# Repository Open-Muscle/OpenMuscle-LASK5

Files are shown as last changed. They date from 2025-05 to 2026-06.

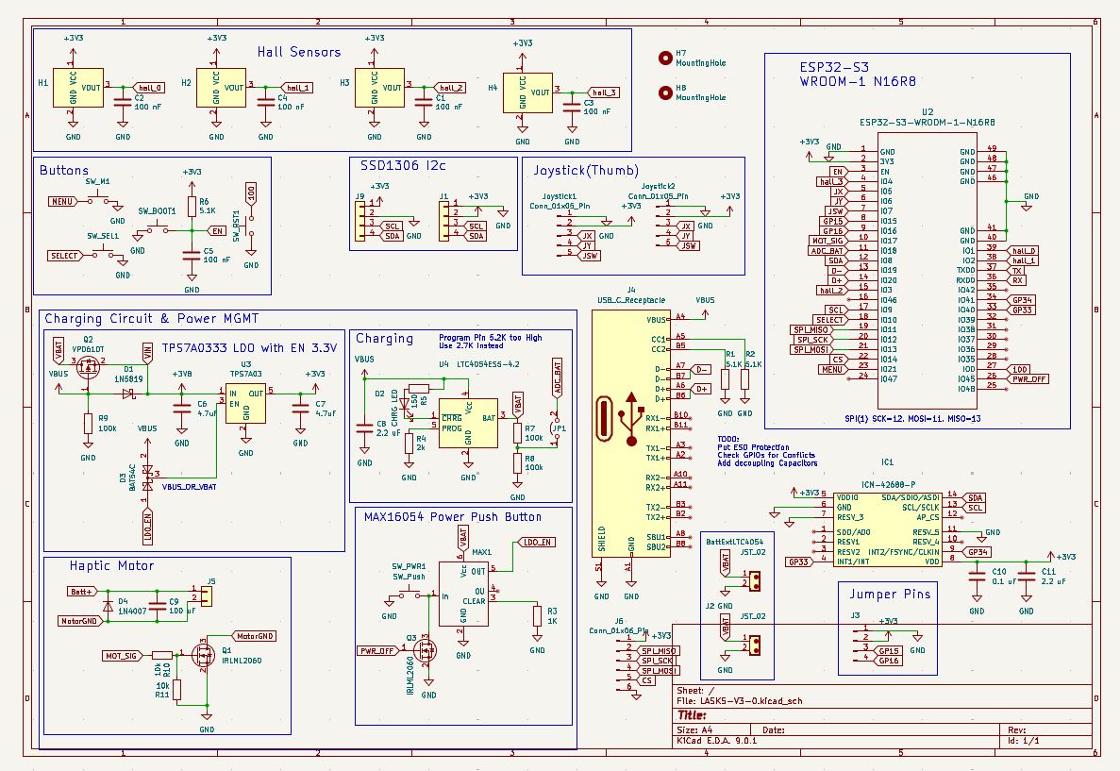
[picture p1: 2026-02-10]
Schematics/Open Muscle Labeler (LASK5) Schematic-V3.jpg

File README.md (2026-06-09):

# LASK5 – A Gloveless Smart Glove Controller






LASK5 is a compact, gloveless smart glove controller designed for robotics, machine learning, and human-computer interaction projects. Originally created to assist with labeling movement data for the [OpenMuscle](https://openmuscle.org) project, this controller is now a fully open-source interface capable of controlling robotic hands, LED sculptures, and more.

```markdown
📌 This device is part of the OpenMuscle ecosystem.  
For project-wide documentation, visit the [OpenMuscle Hub](https://github.com/Open-Muscle/OpenMuscle-Hub).
```

---

## 📽️ Watch the Demo

🎥 **YouTube Video:** [LASK5: The Gloveless Smart Glove](https://youtu.be/DJxaf0ww6us)

---

## 🔧 Features

- ESP32-S3 based (Wi-Fi + ESP-NOW enabled)
- 4-piston finger input with hall sensors
- Thumb joystick
- 128x32 OLED display for menus and feedback
- 4 SMD buttons for UI control
- Modular headers for add-ons (gyroscope, additional sensors)
- Written in MicroPython
- 3D-printable enclosure

---

## 🗂️ Repository Structure

### 🛠️ Hardware (KiCad)

You can find all historical and current KiCad hardware designs under:

📂 [`KiCad/`](https://github.com/Open-Muscle/OpenMuscle-LASK5/tree/main/KiCad)

Each folder contains complete KiCad files, BOMs, and version-specific layout changes.

| Version | Description | Folder |
|---|---|---|
| **v3.0** (Proposed) | New layout with joystick, button updates | [LASK_V3-0](https://github.com/Open-Muscle/OpenMuscle-LASK5/tree/main/KiCad/LASK_V3-0) |
| v2.0 | Button layout revision, early joystick test | [LASK_V2-0](https://github.com/Open-Muscle/OpenMuscle-LASK5/tree/main/KiCad/LASK_V2-0) |
| v1.1 | Original layout with 3-button config | [LASK_V1-1](https://github.com/Open-Muscle/OpenMuscle-LASK5/tree/main/KiCad/LASK_V1-1) |

🧩 Component footprints are stored in:
- [`ESP32WROOMfootprint`](https://github.com/Open-Muscle/OpenMuscle-LASK5/tree/main/KiCad/ESP32WROOMfootprint)
- [`USBfootprint`](https://github.com/Open-Muscle/OpenMuscle-LASK5/tree/main/KiCad/USBfootprint)
- [`ICM-42688-P`](https://github.com/Open-Muscle/OpenMuscle-LASK5/tree/main/KiCad/ICM-42688-P)

---

### 💾 Firmware

The firmware for all LASK versions is maintained centrally in:

📂 [OpenMuscle-Software → `/embedded/lask5`](https://github.com/Open-Muscle/OpenMuscle-Software/tree/main/embedded/LASK5)

> ✅ Be sure to match the firmware branch or directory with your hardware version (see notes in the firmware repo for version compatibility).

---

## 🧠 Use Cases

- Robotic hand control (e.g. HiWonder, Arduino-powered systems)
- LED and kinetic art control
- Machine learning data labeling (OpenMuscle)
- Custom HCI devices, VR/AR control experiments

---

## 🚀 Getting Started

1. Visit the [OpenMuscle Hub](https://github.com/Open-Muscle/OpenMuscle-Hub) for device setup overview.
2. Select your hardware version from the `/KiCad` folder.
3. Follow included assembly instructions (or upcoming guides at [openmuscle.org](https://openmuscle.org)).
4. Flash your ESP32-S3 using the LASK5 firmware from [OpenMuscle-Software](https://github.com/Open-Muscle/OpenMuscle-Software).
5. Power on, test input, and begin using ESP-NOW or serial modes.

---

## 🤝 Contribute

We welcome PRs for hardware, firmware, or documentation.  
You can also submit ideas or questions in [OpenMuscle Discussions](https://github.com/Open-Muscle/OpenMuscle-Hub/discussions) (coming soon).

> If you build your own LASK5 device, let us know!  
> Tag [@OpenMuscle](https://github.com/Open-Muscle) or submit to the Community Builds section.

---

## 📜 License

This repository is covered by a combination of licenses based on content type:

- **Hardware Design Files** (KiCad schematics, PCB layouts, mechanical files):  
  📄 [CERN Open Hardware License v2.0 – Strongly Reciprocal (CERN-OHL-S)](https://ohwr.org/cern_ohl_s_v2.txt)  
  → You may copy, modify, and manufacture hardware as long as you release modifications under the same license.

- **Firmware and Code Snippets** (e.g. MicroPython, setup scripts):  
  📄 [MIT License](https://opensource.org/licenses/MIT)  
  → You may use, modify, and redistribute the code freely with attribution.

- **Art and Visual Media** (e.g. logos, SVGs, diagrams, illustrations):  
  🎨 [Creative Commons Attribution 4.0 International (CC BY 4.0)](https://creativecommons.org/licenses/by/4.0/)  
  → You may use and remix art assets with credit to the original authors.
  
🔍 The hardware license text lives at [LICENSE](LICENSE) (root) and in [LICENSES/](LICENSES/).

---

Made with 💡 by [TURFPTAx](https://github.com/turfptax) for the OpenMuscle initiative.

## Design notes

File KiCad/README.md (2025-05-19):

# LASK5 – OpenMuscle Sensor Device

**Version:** `V3 (Proposed)`  
**Target Microcontroller:** ESP32-S3-WROOM-1-N16R8  
**Project:** OpenMuscle – Biomechanical Sensing for Prosthetics & Robotics  
**Repository:** https://github.com/turfptax/OpenMuscle-Hardware

---

## 📐 Overview

The LASK5 board is a wearable sensor platform for real-time finger movement detection, developed as part of the OpenMuscle project. It integrates Hall effect sensors, a joystick, buttons, a low-power screen, and wireless communication via ESP32-S3.

Version 3 introduces multiple improvements in usability, sensing accuracy, and expandability.

---

## 🚀 New in V3 (Proposed)

| Feature | Description |
|---|---|
| 🔌 USB Detection | VBUS now routed to a GPIO via voltage divider, allowing firmware to detect USB connection. |
| 🔋 USB Boot Without Battery | Modified power logic enables powering on via USB without a battery installed, using diode-based OR logic to control LDO enable line. |
| 📉 Improved ADC Accuracy | Voltage divider for battery monitoring updated to 10k/10k, reducing impedance for better ESP32-S3 ADC readings. |
| 🧭 6-Axis Gyroscope Support | IMU footprint and I²C headers added for optional motion sensing (MPU6050 or ICM-42688). |
| ⚙️ Charging Status Feedback | CHRG pin from LTC4054 connected to GPIO for in-software charge status indication. |

---
## 📦 Block Diagram
```
Battery ─────┐
├─> Charger (LTC4054) ──> Power Rail (+3.3V)
USB ───────┐ │
│ └─> VBUS GPIO (USB Detect)
└───> LDO EN Logic ──> TPS7A0333 LDO ──> ESP32-S3
```
---

## 📊 Hardware Specifications

- **MCU:** ESP32-S3-WROOM-1-N16R8 (dual-core, WiFi/BLE, 16MB flash, 8MB PSRAM)
- **Power:**
  - USB-C with VBUS detection
  - 1-cell LiPo battery
  - TPS7A0333 LDO (3.3V, low quiescent current)
  - MAX16054 latched soft-power button
- **Sensing:**
  - 4x Hall effect analog sensors
  - 1x Joystick (XY + button)
  - 0.96” SSD1306 OLED display (I²C)
  - Optional 6-axis gyro (MPU6050, ICM-42688, etc.)
- **Inputs:**
  - `menu` and `select` tactile buttons
  - Power button
- **Charging:**
  - LTC4054ES5-4.2 Li-Ion charger
  - CHRG status indicator routed to GPIO
- **Communication:**
  - ESP-NOW, WiFi, BLE
- **Headers:**
  - I²C breakout
  - SPI/debug/jumper expansion

---

## 🛠️ Setup & Firmware

- Flash via USB-C using esptool or Micropython.
- Default I²C pins: `SDA=GPIO15`, `SCL=GPIO16`
- ADC battery read: `GPIO4` (adjusted via voltage divider)
- USB detect pin: `GPIO10` *(example)*
- CHRG detect pin: `GPIO11` *(example)*

---

## 📚 Resources

- [OpenMuscle.org](https://openmuscle.org)
- [KiCad Schematic Viewer](https://kicad.org)
- [ESP32-S3 Datasheet](https://www.espressif.com/sites/default/files/documentation/esp32-s3_datashee---

## 🙌 Contributing

Interested in testing or improving the hardware? Submit a pull request or open an issue with your suggestions.

---

## 🧪 Version History

| Version | Date | Notes |
|---|---|---|
| V1 | 2024-02 | Initial prototype, using ESP32-S3 Dev-Kit |
| V2 | 2024-05 | 4-Layer PCB with 4x1 Hall sensors & Joystick |
| V3 | 25-XX | USB logic, gyro, and ADC improvements |

---

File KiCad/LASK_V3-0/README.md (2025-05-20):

# LASK v3 – OpenMuscle Labeler PCB

**Version:** 3.0  
**KiCad Version:** 9.0.1  
**Project Type:** Embedded hardware (ESP32-based controller)  
**Use Case:** Labeling hand movement data for prosthetic machine learning models

This is the third iteration of the LASK (Labeler for Sensor Kit) PCB, designed as part of the OpenMuscle project. LASK v3 is a handheld device used to interact with muscle sensors, label data, and provide haptic and motion feedback during training sessions.

---

## 🧠 Major Additions in v3

- ✅ Added **haptic motor driver** with flyback diode protection  
- ✅ Added **ICM-42688-P IMU** (I²C, with alternate support for SPI)  
- ✅ Enhanced **power management** using a push-button latch and USB auto-power-on  
- ✅ Clean GPIO assignments for consistent firmware development

---

## 🧩 System Overview

| Subsystem | Description |
|---|---|
| **MCU** | ESP32-S3-WROOM-1 (16MB flash, 8MB PSRAM) |
| **Sensors** | 4x Hall effect sensors w/ 100nF capacitors to ground |
| **IMU** | ICM-42688-P (I²C: GPIO8=SDA, GPIO9=SCL) |
| **Display** | SSD1306 OLED (I²C shared) |
| **Input** | 2 buttons (Menu & Select), Thumb joystick w/ push |
| **Output** | Haptic motor driven via MOSFET on GPIO17 |
| **Power** | MAX16054 latch, TPS7A0333 LDO, LTC4054 charger |
| **Interface** | USB-C for charging and programming |

---

## 🧷 GPIO Pinout

| Function | GPIO |
|---|---|
| Hall Sensor 0 | 1 |
| Hall Sensor 1 | 2 |
| Hall Sensor 2 | 3 |
| Hall Sensor 3 | 4 |
| Joystick X | 5 |
| Joystick Y | 6 |
| Joystick Switch | 7 |
| I²C SDA (IMU + OLED) | 8 |
| I²C SCL (IMU + OLED) | 9 |
| Select Button | 10 |
| SPI MISO | 11 |
| SPI SCK | 12 |
| SPI MOSI | 13 |
| Haptic Motor Signal | 17 |
| Battery Voltage ADC | 18 |
| Menu Button | 21 |
| SPI CS (available) | 22 |

---

## 🔋 Power Management

- **Charging:** LTC4054 linear charger via USB-C  
- **Voltage Regulation:** TPS7A0333 LDO with EN pin control  
- **Power-on Logic:** MAX16054 handles push-button latching  
  - **VBUS detection** auto-enables LDO via diode OR circuit  
  - Power can also be toggled with push button  
- **Haptic Driver:** IRLML2060 N-MOSFET, protected by 1N4007 diode

---

## 🛠️ Schematic

LASK v3 Schematic  
> 📁 Located in `/kicad_project/`

---

## 🧪 Development Notes

- Future version may migrate IMU to SPI for better performance
- USB VBUS is sensed to allow automatic boot when plugged in
- Add decoupling capacitors on IMU pins for improved stability (see TODO in schematic)

---

## 📂 Repository Structure

```
/
├── kicad_project/
│ ├── LASKS-V3_0.kicad_sch
│ └── LASKS-V3_0.kicad_pcb
├── docs/
│ └── lask_v3_schematic.png
├── README.md
```

---

## 🔓 License

Open-source under [CERN-OHL-W v2](https://ohwr.org/project/cernohl/wikis/CERN-OHL-version-2)  
Part of the [OpenMuscle Project](https://openmuscle.org)

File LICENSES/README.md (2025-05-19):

# License Overview – OpenMuscle LASK5

This repository contains **open source hardware** and **firmware** developed as part of the OpenMuscle project.

## 🧩 Hardware License

All KiCad PCB files, schematic files, and mechanical designs in this repository are licensed under the:

📄 **CERN Open Hardware License v2 – Strongly Reciprocal (CERN-OHL-S)**  
You can copy, modify, and distribute the hardware as long as you share source files under the same license.

Full license text: [`LICENSES/CERN-OHL-S-2.0.txt`](./LICENSES/CERN-OHL-S-2.0.txt)  
More info: [https://ohwr.org/cern_ohl](https://ohwr.org/cern_ohl)

> Attribution Required: Please credit the OpenMuscle project in derivative works or publications.

## 💾 Firmware License

Firmware and MicroPython code is licensed under the permissive:

📄 **MIT License**

You can use this code freely in commercial or personal projects with attribution.

Full text: [`LICENSES/MIT.txt`](./LICENSES/MIT.txt)

## 📚 Documentation

If not explicitly stated, all written documentation (README files, build instructions, etc.) is shared under **CERN-OHL-S v2.0** along with the hardware.

## 🤝 Contributing

By contributing, you agree to license your work under the same terms.

For any questions about licensing or commercial reuse, contact: [https://openmuscle.org](https://openmuscle.org)

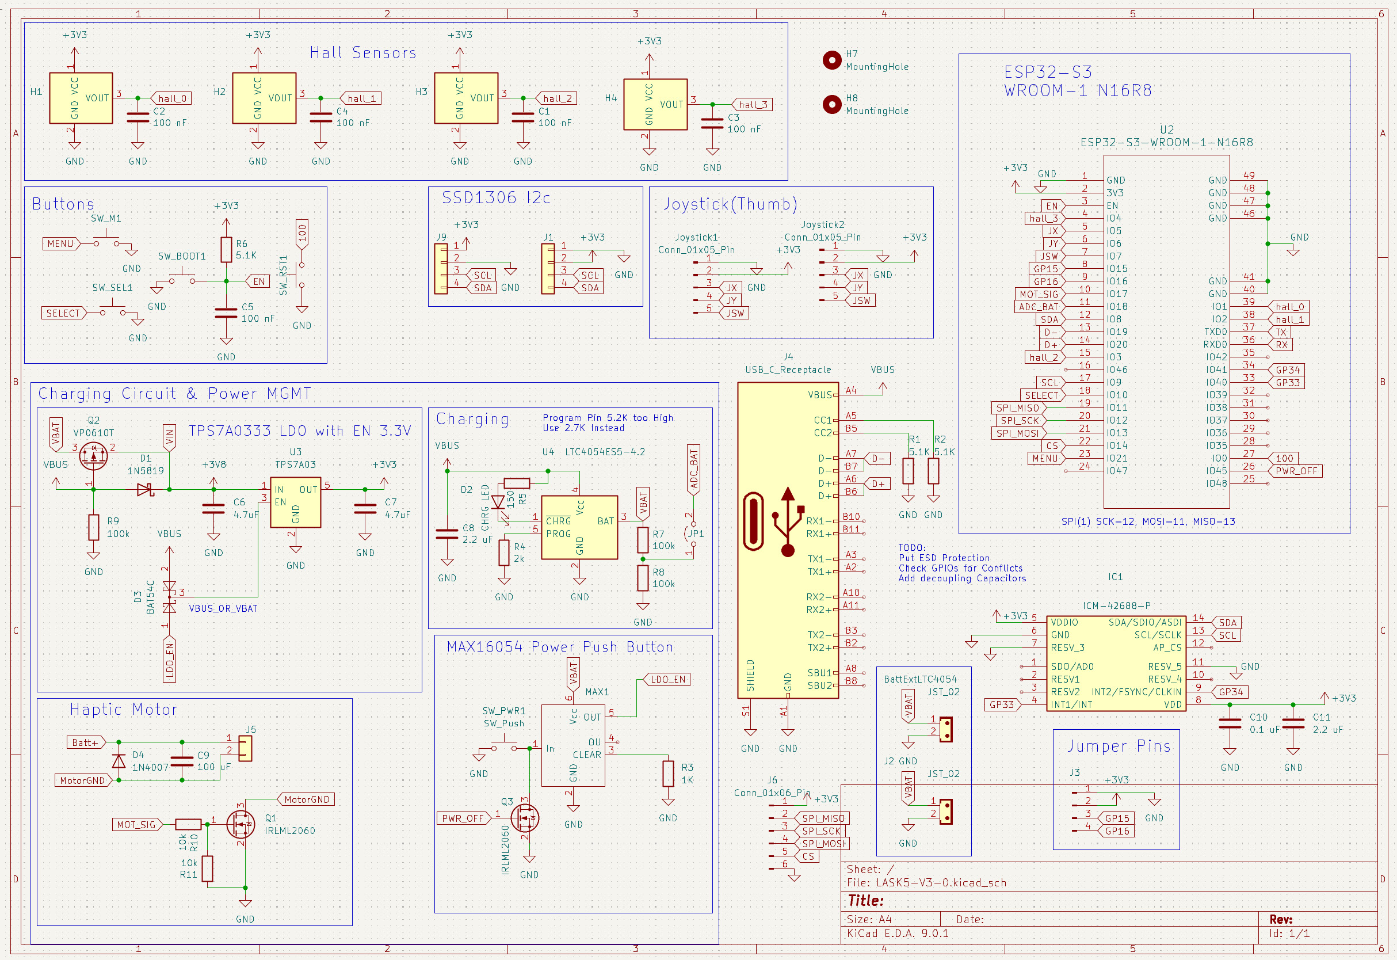
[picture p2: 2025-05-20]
KiCad/LASK_V3-0/images/LASK5-V3-Schematic.jpg

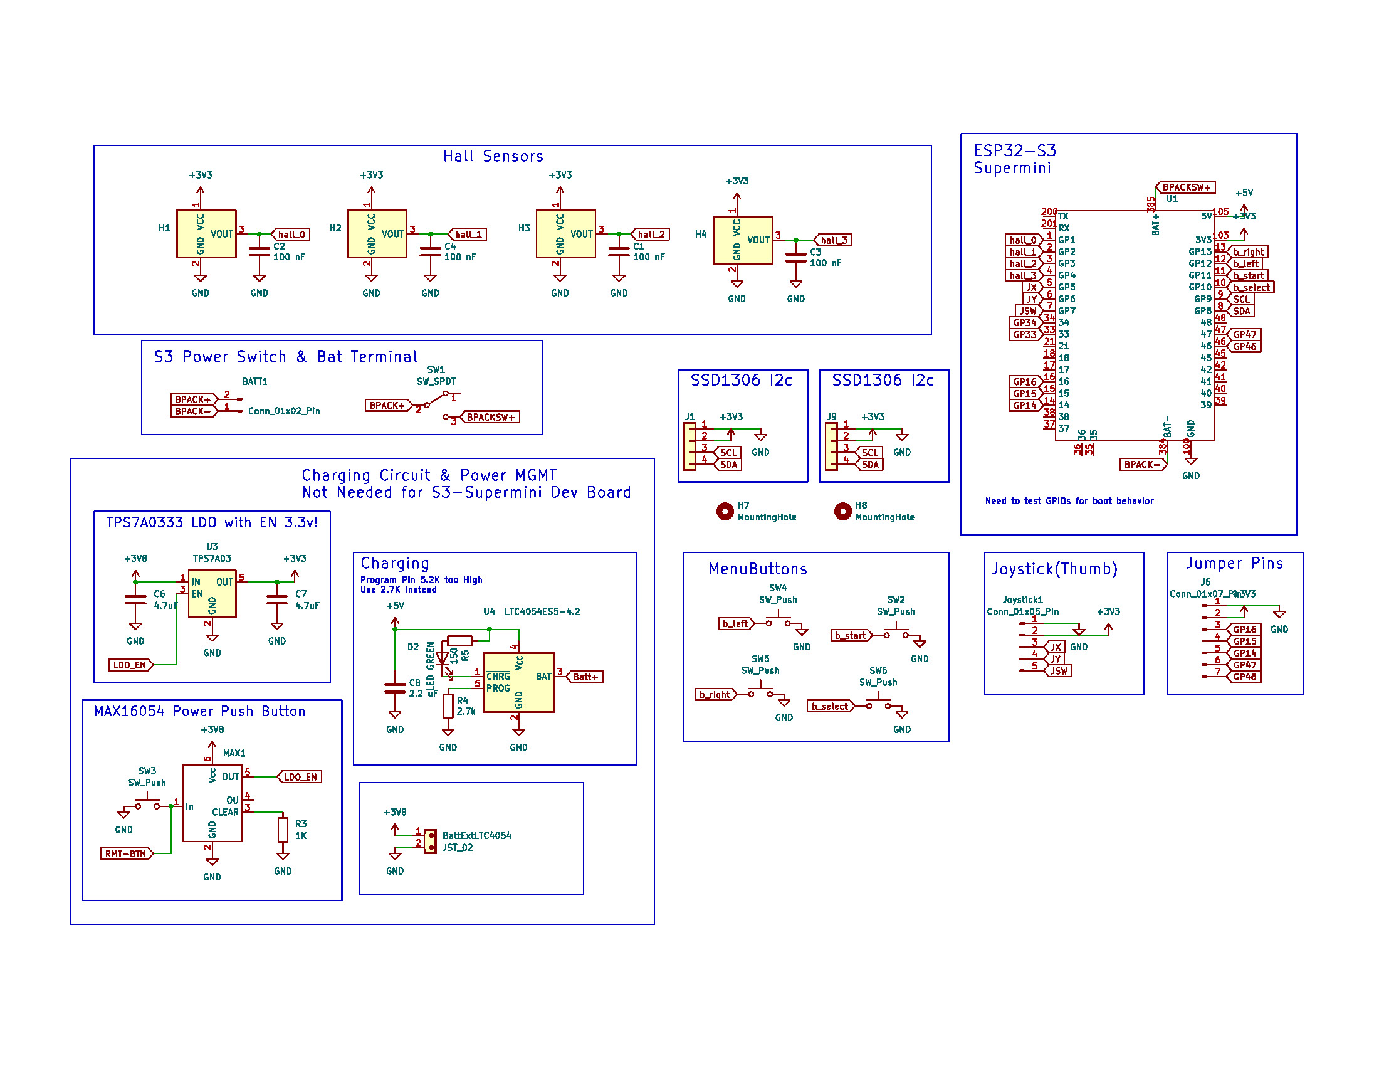
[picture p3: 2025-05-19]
Schematics/Open Muscle Labeler (LASK5) Schematic.jpg

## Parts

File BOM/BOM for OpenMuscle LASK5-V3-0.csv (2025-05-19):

Source: | D:\MT2-TX\OneDrive - TURFPTAx\Documents\GitHub\OpenMuscle-LASK5\KiCad\LASK_V3-0\LASK5-V3-0.kicad_sch
Date: | 2025-05-19T15:46:47-0500
Tool: | Eeschema 9.0.1
Generator: | C:\Program Files\KiCad\9.0\bin\scripting\plugins/bom_csv_grouped_by_value_with_fp.py
Component Count: | 56
Ref | Qnty | Value | Cmp name | Footprint | Description | Vendor | DNP
BattExtLTC4054 | 1 | JST_02 | JST_02 | Connector_JST:JST_EH_B2B-EH-A_1x02_P2.50mm_Vertical | JST Connector 2 pins
C1, C2, C3, C4, C5 | 5 | 100 nF | C | Capacitor_SMD:C_0402_1005Metric | Unpolarized capacitor
C6, C7 | 2 | 4.7uF | C | Capacitor_SMD:C_0805_2012Metric | Unpolarized capacitor
C8, C11 | 2 | 2.2 uF | C | Capacitor_SMD:C_0603_1608Metric | Unpolarized capacitor
C9 | 1 | 100 uF | C | Capacitor_SMD:C_0603_1608Metric | Unpolarized capacitor
C10 | 1 | 0.1 uF | C | Capacitor_SMD:C_0603_1608Metric | Unpolarized capacitor
D1 | 1 | 1N5819 | 1N5819 | Diode_SMD:D_SOD-123F | 40V 1A Schottky Barrier Rectifier Diode, DO-41
D2 | 1 | CHRG LED | LED | LED_SMD:LED_0805_2012Metric | LED generic
D3 | 1 | BAT54C | BAT54C | Package_TO_SOT_SMD:SOT-23 | dual schottky barrier diode, common cathode
D4 | 1 | 1N4007 | 1N4007 | Diode_SMD:D_SOD-123 | 1000V 1A General Purpose Rectifier Diode, DO-41
H1, H2, H3, H4 | 4 | A1369xUA-10 | A1369xUA-10 | Connector_PinHeader_2.00mm:PinHeader_1x03_P2.00mm_Vertical | Programmable Linear Hall Effect Sensor, -8.5 to -12.5mV/G, SIP-3
H7, H8 | 2 | MountingHole | MountingHole | MountingHole:MountingHole_2.2mm_M2 | Mounting Hole without connection
IC1 | 1 | ICM-42688-P | ICM-42688-P | IIM42352 | IMU 6-Axis
J1, J9 | 2 | Conn_01x04 | Conn_01x04 | Connector_PinHeader_2.54mm:PinHeader_1x04_P2.54mm_Vertical | Generic connector, single row, 01x04, script generated (kicad-library-utils/schlib/autogen/connector/)
J2 | 1 | JST_02 | JST_02 | Connector_JST:JST_EH_B2B-EH-A_1x02_P2.50mm_Vertical | JST Connector 2 pins
J3 | 1 | Conn_01x04_Pin | Conn_01x04_Pin | Connector_PinHeader_2.00mm:PinHeader_1x04_P2.00mm_Vertical | Generic connector, single row, 01x04, script generated
J4 | 1 | USB_C_Receptacle | USB_C_Receptacle | Connector_USB:USB_C_Receptacle_HRO_TYPE-C-31-M-12 | USB Full-Featured Type-C Receptacle connector
J5 | 1 | Conn_01x02 | Conn_01x02 | Connector_PinHeader_2.00mm:PinHeader_1x02_P2.00mm_Vertical | Generic connector, single row, 01x02, script generated (kicad-library-utils/schlib/autogen/connector/)
J6 | 1 | Conn_01x06_Pin | Conn_01x06_Pin | Connector_PinHeader_1.27mm:PinHeader_1x06_P1.27mm_Vertical | Generic connector, single row, 01x06, script generated
Joystick1, Joystick2 | 2 | Conn_01x05_Pin | Conn_01x05_Pin | Connector_PinHeader_2.00mm:PinHeader_1x05_P2.00mm_Vertical | Generic connector, single row, 01x05, script generated
JP1 | 1 | Jumper_2_Open | Jumper_2_Open | Jumper:SolderJumper-2_P1.3mm_Open_TrianglePad1.0x1.5mm | Jumper, 2-pole, open
MAX1 | 1 | MAX16054AZT | MAX16054 | Package_TO_SOT_SMD:SOT-23-6
Q1, Q3 | 2 | IRLML2060 | IRLML2060 | Package_TO_SOT_SMD:SOT-23 | 1.2A Id, 60V Vds, 480mOhm Rds, N-Channel HEXFET Power MOSFET, SOT-23
Q2 | 1 | VP0610T | VP0610T | Package_TO_SOT_SMD:SOT-23 | -0.18A Id, -60V Vds, P-Channel MOSFET, SOT-23
R1, R2, R6 | 3 | 5.1K | R | Resistor_SMD:R_0603_1608Metric | Resistor
R3 | 1 | 1K | R | Resistor_SMD:R_0603_1608Metric | Resistor
R4 | 1 | 2k | R | Resistor_SMD:R_0603_1608Metric | Resistor
R5 | 1 | 150 | R | Resistor_SMD:R_0603_1608Metric | Resistor
R7, R8, R9 | 3 | 100k | R | Resistor_SMD:R_0603_1608Metric | Resistor
R10, R11 | 2 | 10k | R | Resistor_SMD:R_0603_1608Metric | Resistor
SW_BOOT1 | 1 | SW_Push | SW_Push | OpenMuscleDevKit:EVQP2P02M | Push button switch, generic, two pins
SW_M1 | 1 | SW_Push | SW_Push | OpenMuscleDevKit:EVQP2P02M | Push button switch, generic, two pins
SW_PWR1 | 1 | SW_Push | SW_Push | OpenMuscleDevKit:EVQP2P02M | Push button switch, generic, two pins
SW_RST1 | 1 | SW_Push | SW_Push | OpenMuscleDevKit:EVQP2P02M | Push button switch, generic, two pins
SW_SEL1 | 1 | SW_Push | SW_Push | OpenMuscleDevKit:EVQP2P02M | Push button switch, generic, two pins
U2 | 1 | ESP32-S3-WROOM-1-N16R8 | ESP32-S3-WROOM-1-N16R8 | footprints:ESP32-S3-WROOM-1_EXP
U3 | 1 | TPS7A03 | TPS7A0508PDBV | Package_TO_SOT_SMD:SOT-23-5 | 200-mA Ultra-Low-Iq LDO, 0.8V, SOT-23-5
U4 | 1 | LTC4054ES5-4.2 | LTC4054ES5-4.2 | Package_TO_SOT_SMD:TSOT-23-5 | Constant-current/constant-voltage linear charger for single cell lithium-ion batteries with 2.9V Trickle Charge, 4.5V to 6.5V VDD, -40 to +85 degree Celsius, TSOT-23-5

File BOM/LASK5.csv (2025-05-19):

Id | Designator | Footprint | Quantity | Designation | Supplier and ref
1 | C2,C4,C3,C1 | C_0402_1005Metric | 4 | 100 nF
2 | R4 | R_0603_1608Metric | 1 | 2.7k
3 | C6,C7 | C_0805_2012Metric | 2 | 4.7uF
4 | U4 | TSOT-23-5 | 1 | LTC4054ES5-4.2
5 | SW4,SW3,SW6,SW5,SW2 | EVQP2P02M | 5 | SW_Push
6 | J9,J1 | PinHeader_1x04_P2.54mm_Vertical | 2 | Conn_01x04
7 | Joystick1 | PinHeader_1x05_P2.54mm_Vertical | 1 | Conn_01x05_Pin
8 | H2,H4,H1,H3 | PinHeader_1x03_P2.00mm_Vertical | 4 | A1369xUA-10
9 | C8 | C_0603_1608Metric | 1 | 2.2 uF
10 | U3 | SOT-23-5 | 1 | TPS7A03
11 | R3 | R_0603_1608Metric | 1 | 1K
12 | H8,H7 | MountingHole_2.2mm_M2 | 2 | MountingHole
13 | SW1 | PinHeader_1x03_P2.54mm_Vertical | 1 | SW_SPDT
14 | J6 | PinHeader_1x07_P2.54mm_Vertical | 1 | Conn_01x07_Pin
15 | BattExtLTC4054 | JST_EH_B2B-EH-A_1x02_P2.50mm_Vertical | 1 | JST_02
16 | D2 | LED_0805_2012Metric | 1 | LED GREEN
17 | R5 | R_0603_1608Metric | 1 | 150
18 | U1 | ESP32-S3-Super Mini | 1 | ~
19 | MAX1 | SOT-23-6 | 1 | ~
20 | BATT1 | PinHeader_1x02_P2.54mm_Vertical | 1 | Conn_01x02_Pin

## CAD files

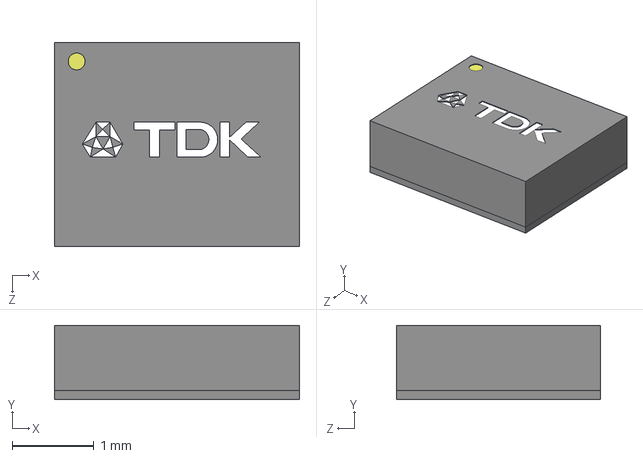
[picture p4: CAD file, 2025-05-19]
KiCad/ICM-42688-P/ICM-42688-P/3D/ICM-42688-P.stp
3.00 x 0.91 x 2.50 mm

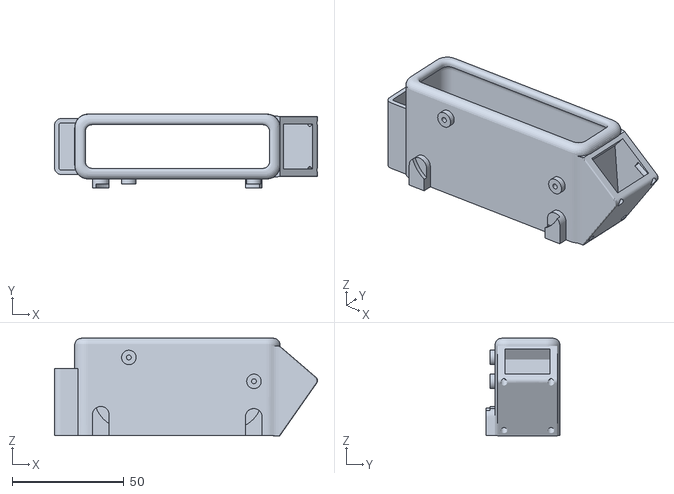
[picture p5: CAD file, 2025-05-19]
STLs/LASK5-JoyThumb.stl
117.5 x 33.0 x 43.6

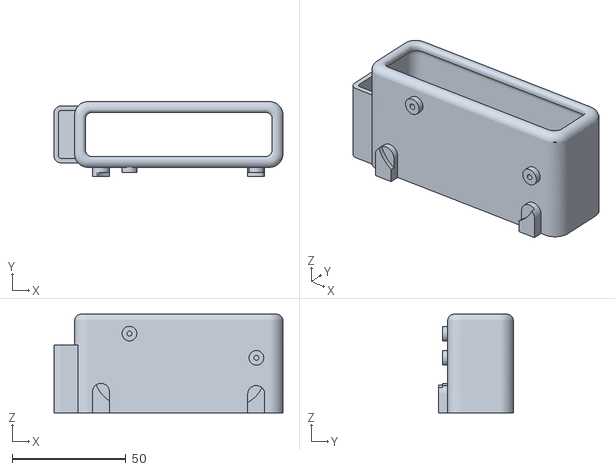
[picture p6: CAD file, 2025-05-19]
STLs/LASK5-BatteryHolder.stl
100.8 x 33.0 x 43.5

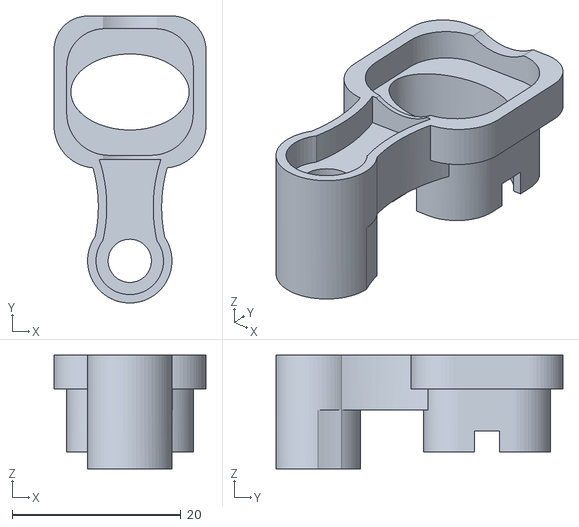
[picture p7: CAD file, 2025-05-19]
STLs/Labeler Depressor.stl
18.0 x 34.0 x 13.5

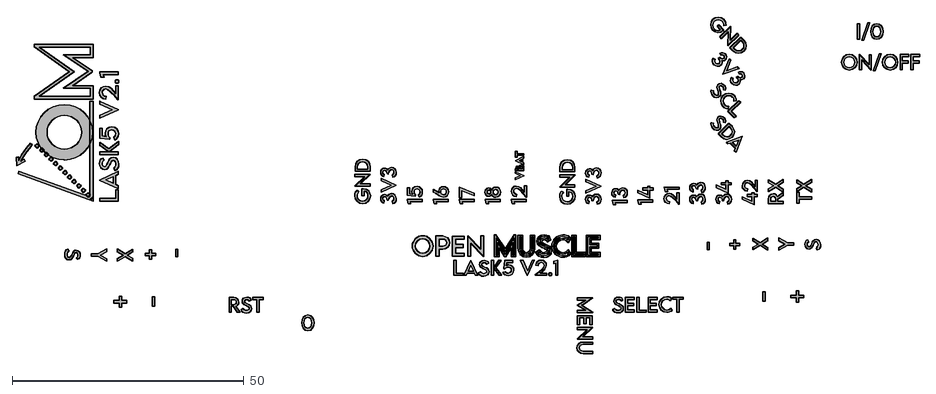
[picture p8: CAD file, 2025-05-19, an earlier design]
KiCad/LASK_V2-0/LASK5-2-1-Design-TESTTTT.dxf
195.0 x 72.7

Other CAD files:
KiCad/ICM-42688-P/ICM-42688-P/Allegro/iim42352.psm
KiCad/ICM-42688-P/ICM-42688-P/DEHDL/icm_42688_p/chips/chips.prt

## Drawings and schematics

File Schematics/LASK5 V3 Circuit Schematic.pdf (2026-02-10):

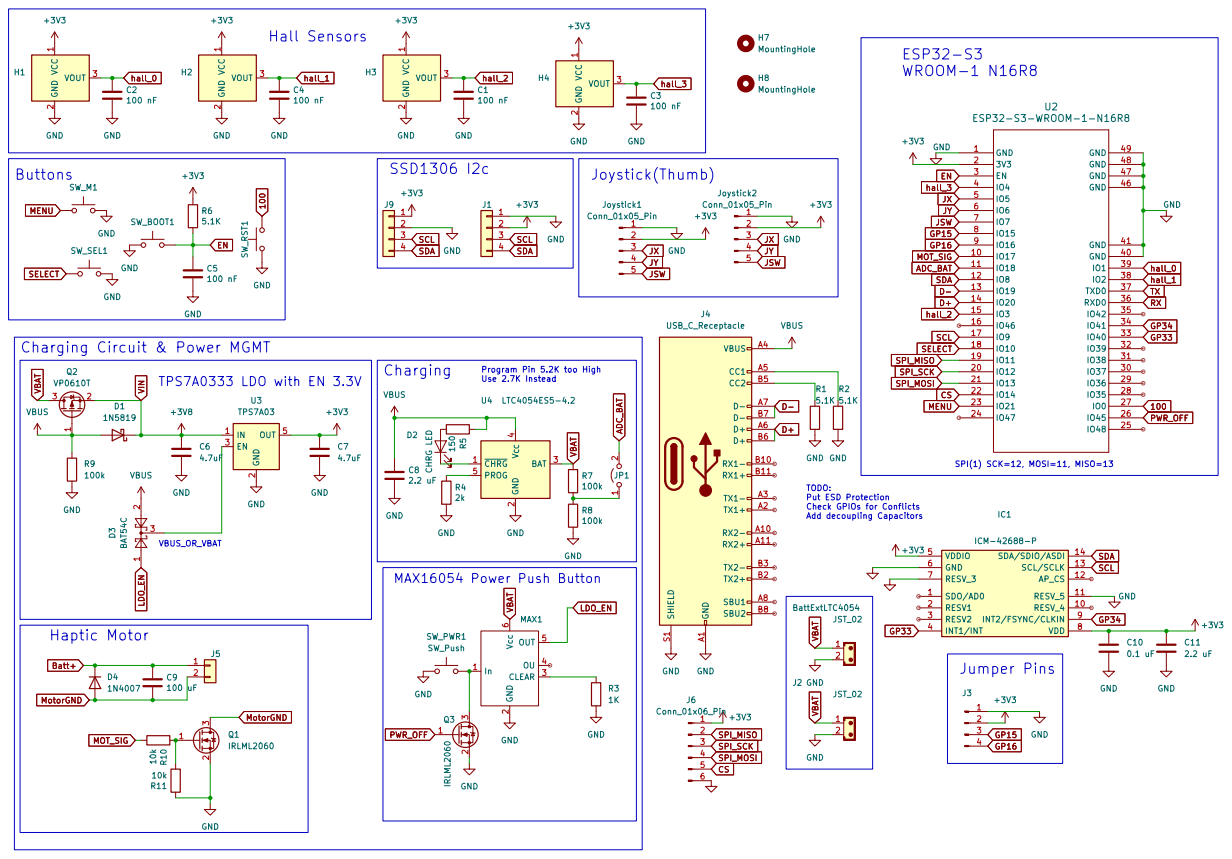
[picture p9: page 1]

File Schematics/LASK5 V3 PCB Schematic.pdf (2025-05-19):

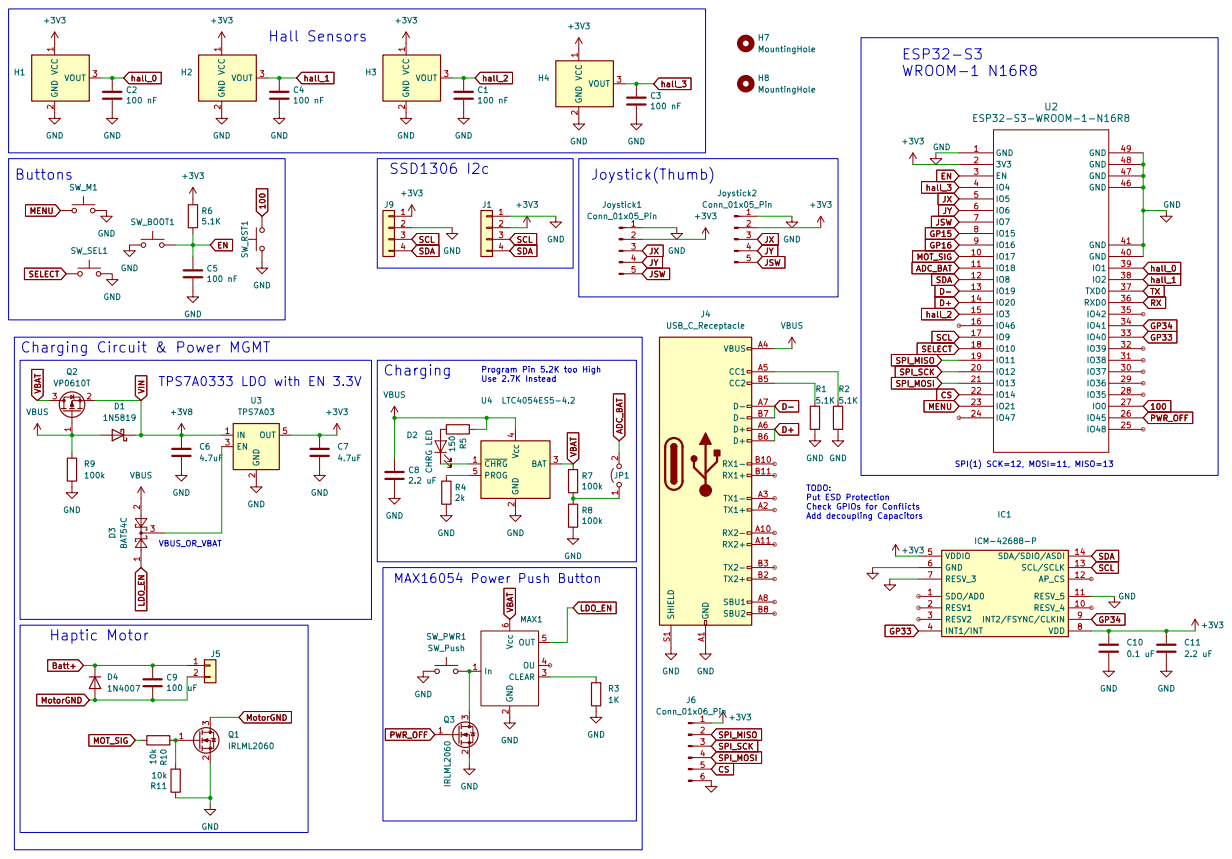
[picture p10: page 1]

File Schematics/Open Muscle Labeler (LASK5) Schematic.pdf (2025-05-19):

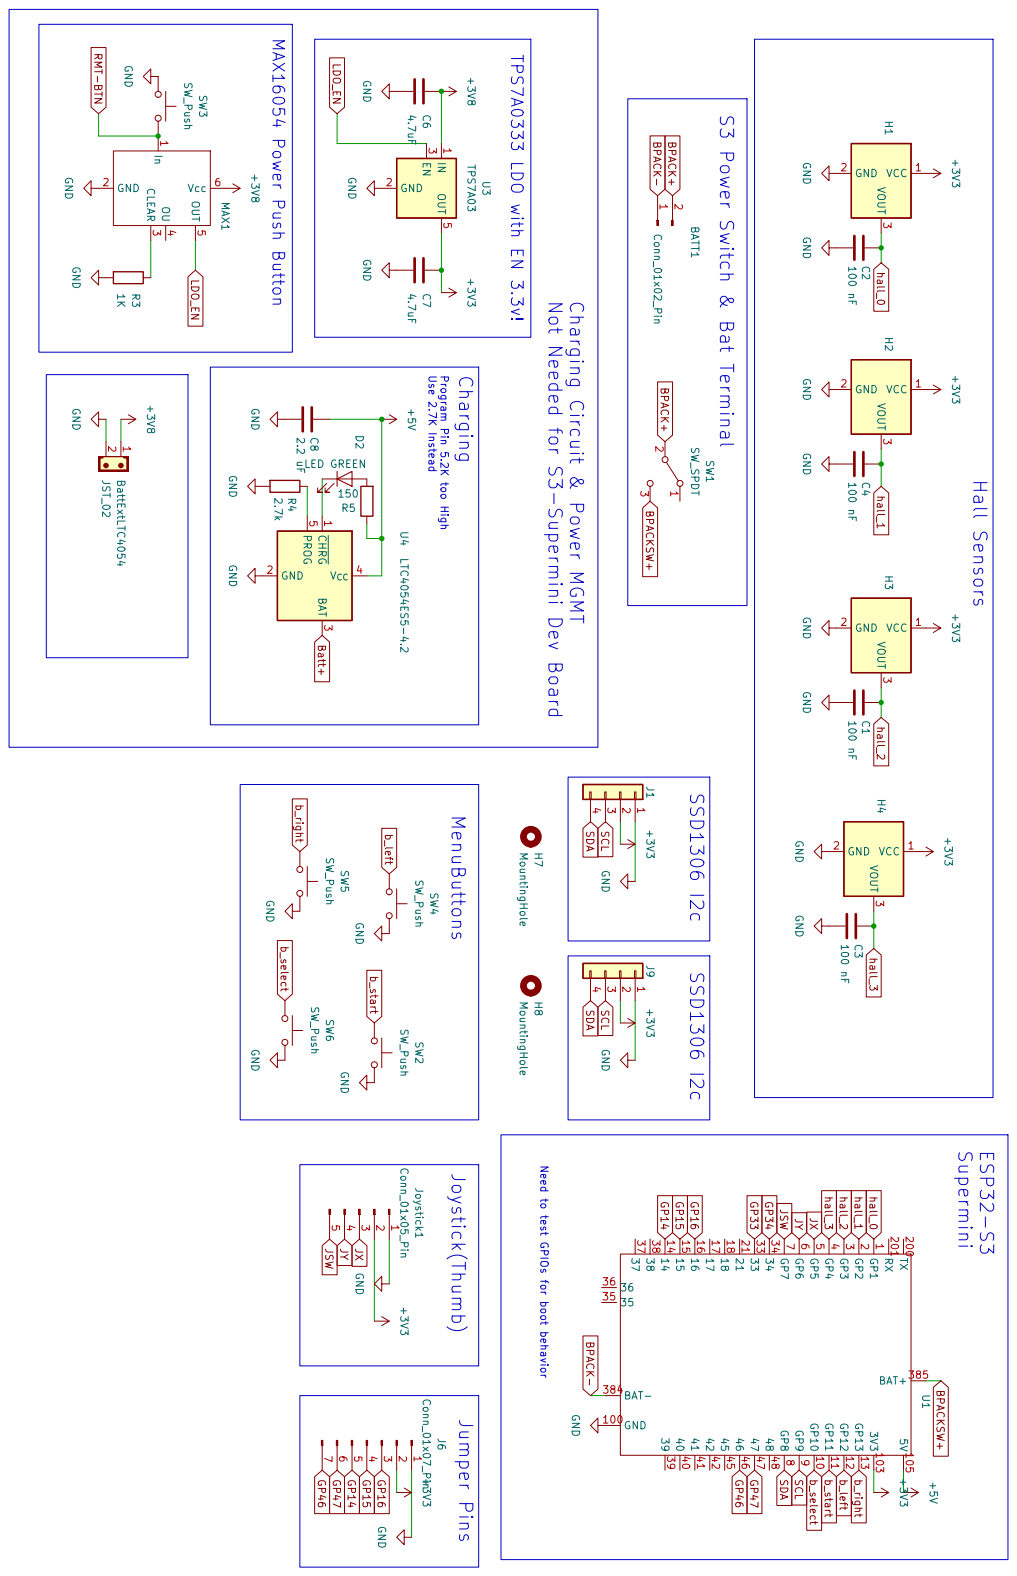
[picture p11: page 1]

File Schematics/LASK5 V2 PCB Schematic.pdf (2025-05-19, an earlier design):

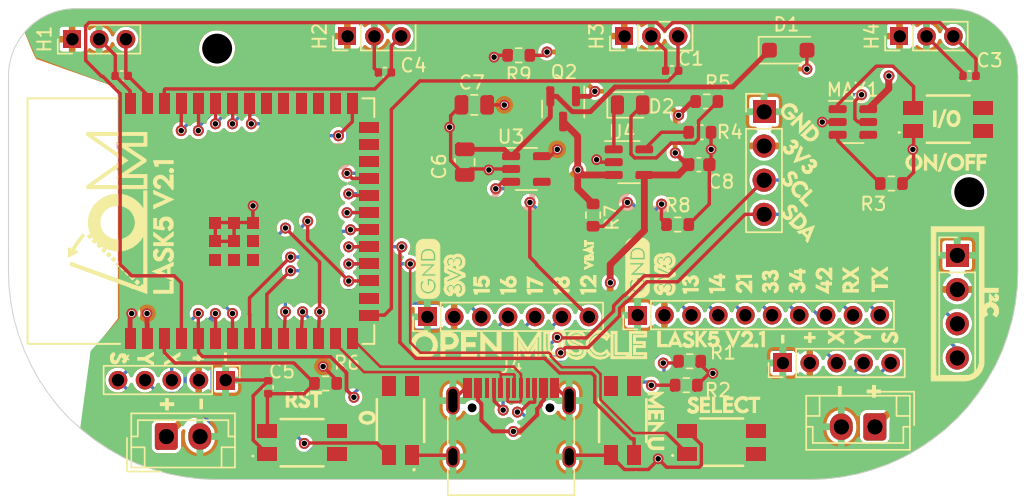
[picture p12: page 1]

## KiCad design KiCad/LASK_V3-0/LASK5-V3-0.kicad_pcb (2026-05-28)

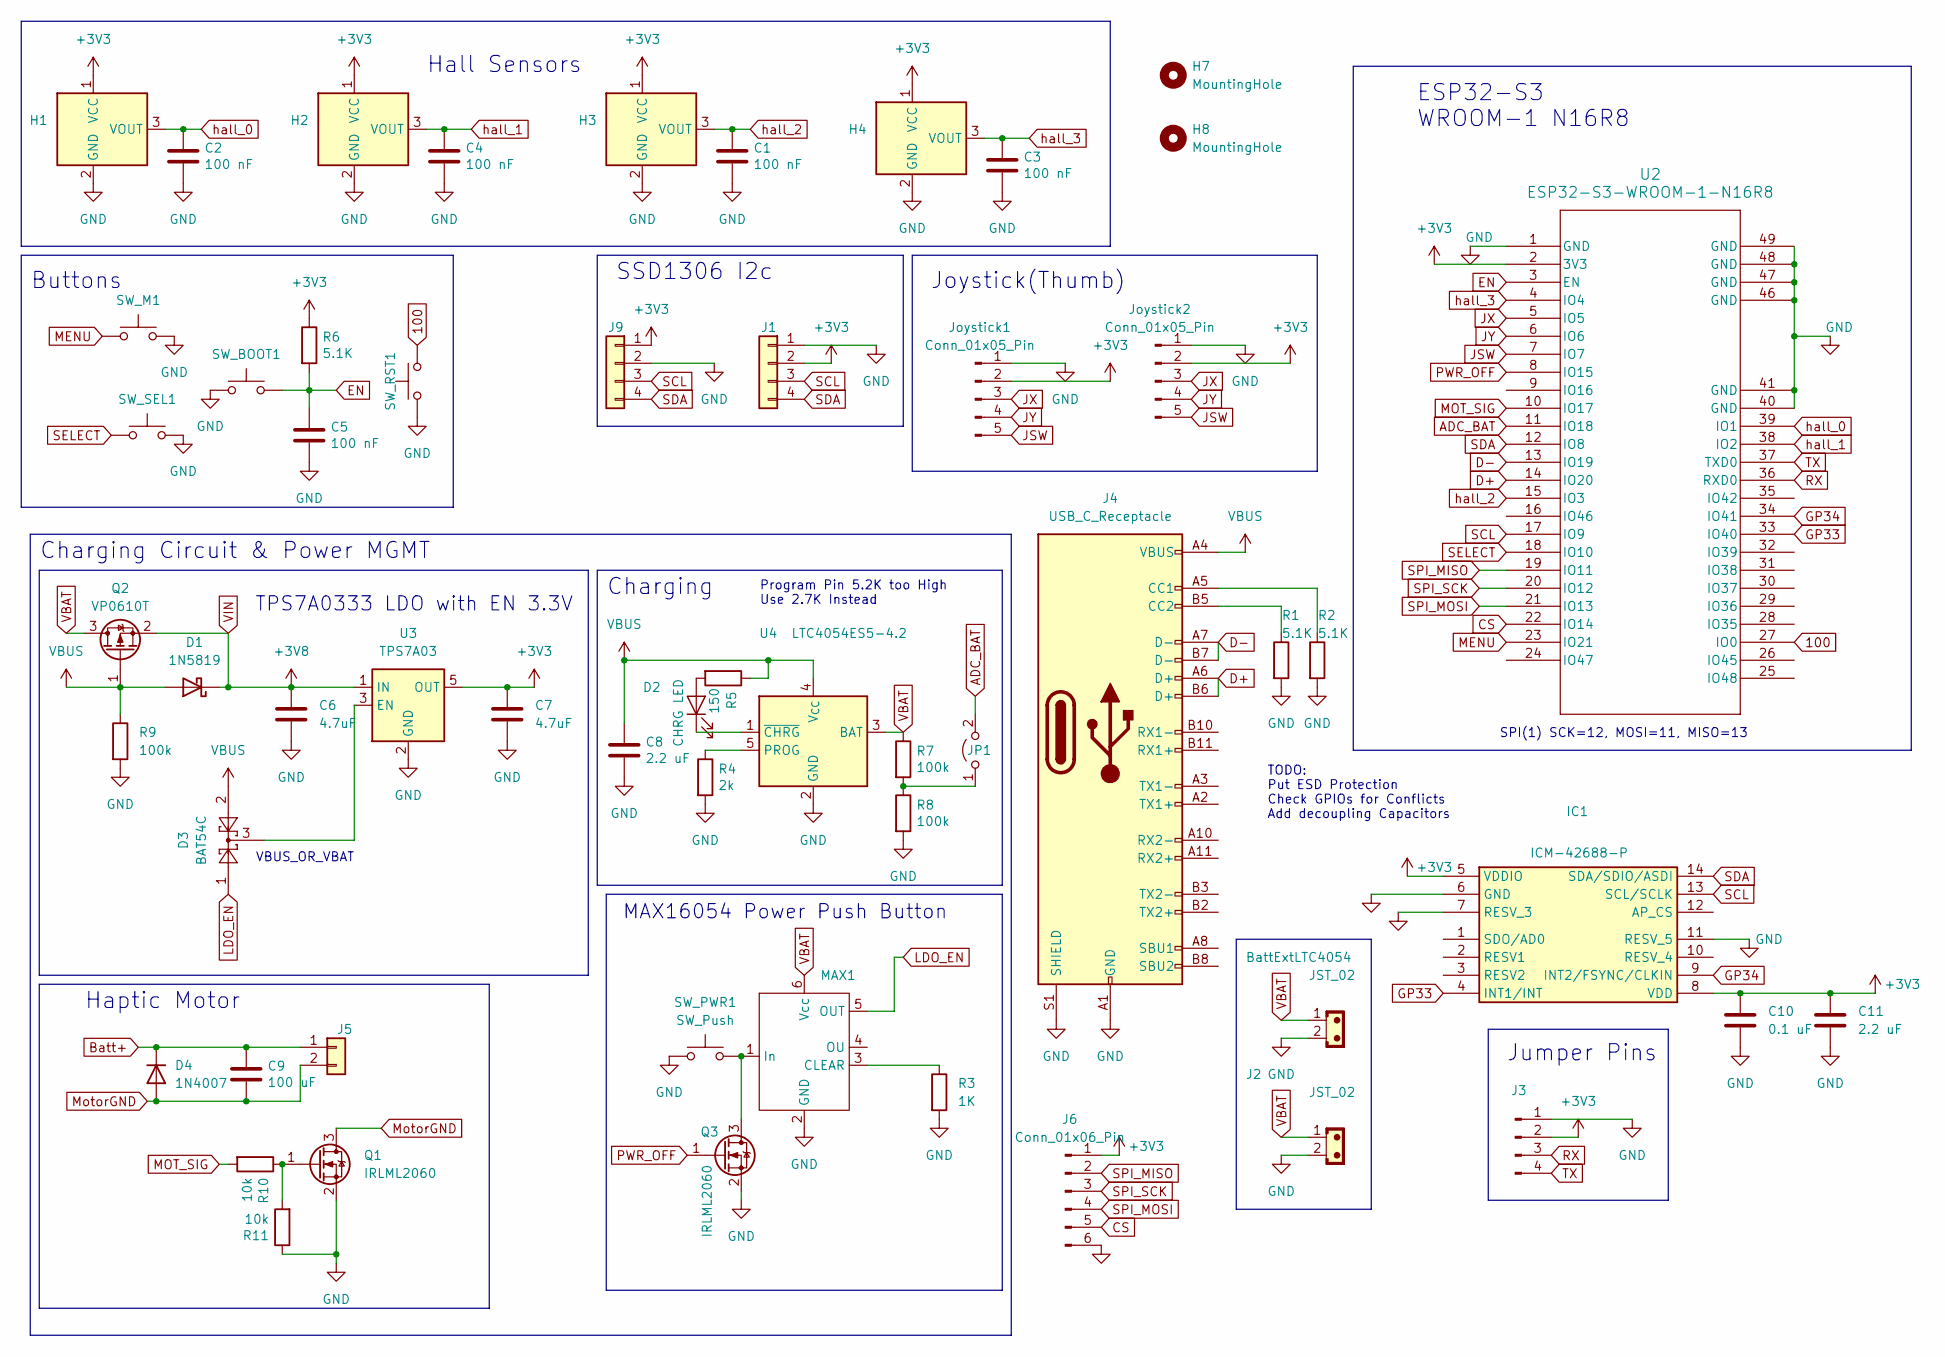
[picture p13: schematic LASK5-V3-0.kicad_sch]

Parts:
BattExtLTC4054: JST_02; JST_EH_B2B-EH-A_1x02_P2.50mm_Vertical
C1, C2, C3, C4, C5: 100 nF; C_0603_1608Metric; JLCPN C1525
C6, C7: 4.7uF; C_0805_2012Metric
C8: 2.2 uF; C_0603_1608Metric; JLCPN C12530
C9: 100 uF; C_0603_1608Metric; JLCPN C12530
C10: 0.1 uF; C_0603_1608Metric
C11: 2.2 uF; C_0603_1608Metric
D1: 1N5819; D_SOD-123F
D2: CHRG LED; LED_0805_2012Metric; JLCPN C72043
D3: BAT54C; SOT-23
D4: 1N4007; D_SOD-123
H1, H2, H3, H4: A1369xUA-10; PinHeader_1x03_P2.00mm_Vertical
H7, H8: MountingHole; MountingHole_2.2mm_M2
IC1: ICM-42688-P; IIM42352; Mouser Part Number 410-ICM-42688-P
J1, J9: Conn_01x04; PinHeader_1x04_P2.54mm_Vertical
J2: JST_02; JST_EH_B2B-EH-A_1x02_P2.50mm_Vertical
J3: Conn_01x04_Pin; PinHeader_1x04_P2.00mm_Vertical
J4: USB_C_Receptacle; USB_C_Receptacle_HRO_TYPE-C-31-M-12
J5: Conn_01x02; PinHeader_1x02_P2.00mm_Vertical
J6: Conn_01x06_Pin; PinHeader_1x06_P1.27mm_Vertical
JP1: Jumper_2_Open; SolderJumper-2_P1.3mm_Open_TrianglePad1.0x1.5mm
Joystick1, Joystick2: Conn_01x05_Pin; PinHeader_1x05_P2.00mm_Vertical
MAX1: SOT-23-6
Q1, Q3: IRLML2060; SOT-23
Q2: VP0610T; SOT-23
R1, R2, R6: 5.1K; R_0603_1608Metric; JLCPN C25905
R3: 1K; R_0603_1608Metric
R4: 2k; R_0603_1608Metric; JLCPN C25905
R5: 150; R_0603_1608Metric; JLCPN C4109
R7, R8: 100k; R_0603_1608Metric; JLCPN C25905
R9: 100k; R_0603_1608Metric
R10, R11: 10k; R_0603_1608Metric; JLCPN C25744
SW_BOOT1: SW_Push; EVQP2P02M
SW_M1: SW_Push; EVQP2P02M
SW_PWR1: SW_Push; EVQP2P02M
SW_RST1: SW_Push; EVQP2P02M
SW_SEL1: SW_Push; EVQP2P02M
U2: ESP32-S3-WROOM-1-N16R8; ESP32-S3-WROOM-1_EXP
U3: TPS7A03; SOT-23-5
U4: LTC4054ES5-4.2; TSOT-23-5

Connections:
100: SW_RST1.2, U2.27 (IO0)
+3V3: C7.1, C10.1, C11.1, H1.1 (VCC), H2.1 (VCC), H3.1 (VCC), H4.1 (VCC), IC1.5 (VDDIO), IC1.8 (VDD), J1.2, J3.2, J6.1, J9.1, Joystick1.2, Joystick2.2, R6.1, U2.2 (3V3), U3.5 (OUT)
ADC_BAT: JP1.2 (B), U2.11 (IO18)
Batt+: C9.2, D4.1 (K), J5.1
CS: J6.5, U2.22 (IO14)
D+: J4.A6 (D+), J4.B6 (D+), U2.14 (IO20)
D-: J4.A7 (D-), J4.B7 (D-), U2.13 (IO19)
EN: C5.2, R6.2, SW_BOOT1.2, U2.3 (EN)
GND: BattExtLTC4054.2, C1.1, C2.1, C3.1, C4.1, C5.1, C6.2, C7.2, C8.1, C10.2, C11.2, H1.2 (GND), H2.2 (GND), H3.2 (GND), H4.2 (GND), IC1.6 (GND), IC1.7 (RESV_3), IC1.11 (RESV_5), J1.1, J2.2, J3.1, J4.A1 (GND), J4.A12 (GND), J4.B1 (GND), J4.B12 (GND), J4.S1 (SHIELD), J6.6, J9.2, Joystick1.1, Joystick2.1, MAX1.2 (GND), Q1.2 (S), Q3.2 (S), R1.2, R2.2, R3.2, R4.2, R8.2, R9.2, R11.1, SW_BOOT1.1, SW_M1.2, SW_PWR1.1, SW_RST1.1, SW_SEL1.2, U2.1 (GND), U2.40 (GND), U2.41 (GND), U2.46 (GND), U2.47 (GND), U2.48 (GND), U2.49 (GND), U3.2 (GND), U4.2 (GND)
GP33: IC1.4 (INT1/INT), U2.33 (IO40)
GP34: IC1.9 (INT2/FSYNC/CLKIN), U2.34 (IO41)
JSW: Joystick1.5, Joystick2.5, U2.7 (IO7)
JX: Joystick1.3, Joystick2.3, U2.5 (IO5)
JY: Joystick1.4, Joystick2.4, U2.6 (IO6)
LDO_EN: D3.1, MAX1.5 (OUT)
MENU: SW_M1.1, U2.23 (IO21)
MOT_SIG: R10.2, U2.10 (IO17)
MotorGND: C9.1, D4.2 (A), J5.2, Q1.3 (D)
unnamed: D2.2 (A), R5.2
unnamed: D2.1 (K), U4.1 (~CHRG)
unnamed: J4.A5 (CC1), R2.1
unnamed: J4.B5 (CC2), R1.1
unnamed: JP1.1 (A), R7.2, R8.1
unnamed: MAX1.3 (CLEAR), R3.1
unnamed: MAX1.1 (In), Q3.3 (D), SW_PWR1.2
unnamed: Q1.1 (G), R10.1, R11.2
unnamed: D3.3, U3.3 (EN)
unnamed: R4.1, U4.5 (PROG)
PWR_OFF: Q3.1 (G), U2.8 (IO15)
RX: J3.3, U2.36 (RXD0)
SCL: IC1.13 (SCL/SCLK), J1.3, J9.3, U2.17 (IO9)
SDA: IC1.14 (SDA/SDIO/ASDI), J1.4, J9.4, U2.12 (IO8)
SELECT: SW_SEL1.1, U2.18 (IO10)
SPI_MISO: J6.2, U2.19 (IO11)
SPI_MOSI: J6.4, U2.21 (IO13)
SPI_SCK: J6.3, U2.20 (IO12)
TX: J3.4, U2.37 (TXD0)
VBAT: BattExtLTC4054.1, J2.1, MAX1.6 (Vcc), Q2.3 (D), R7.1, U4.3 (BAT)
VBUS: C8.2, D1.2 (A), D3.2, J4.A4 (VBUS), J4.A9 (VBUS), J4.B4 (VBUS), J4.B9 (VBUS), Q2.1 (G), R5.1, R9.1, U4.4 (V_{CC})
VIN: C6.1, D1.1 (K), Q2.2 (S), U3.1 (IN)
hall_0: C2.2, H1.3 (VOUT), U2.39 (IO1)
hall_1: C4.2, H2.3 (VOUT), U2.38 (IO2)
hall_2: C1.2, H3.3 (VOUT), U2.15 (IO3)
hall_3: C3.2, H4.3 (VOUT), U2.4 (IO4)

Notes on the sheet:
Jumper Pins
SPI(1) SCK=12, MOSI=11, MISO=13
Buttons
MAX16054 Power Push Button
Joystick(Thumb)
Program Pin 5.2K too High Use 2.7K Instead
Charging
ESP32-S3 WROOM-1 N16R8
Charging Circuit & Power MGMT
SSD1306 I2c
TODO: Put ESD Protection Check GPIOs for Conflicts Add decoupling Capacitors
TPS7A0333 LDO with EN 3.3V
Hall Sensors
VBUS_OR_VBAT
Haptic Motor

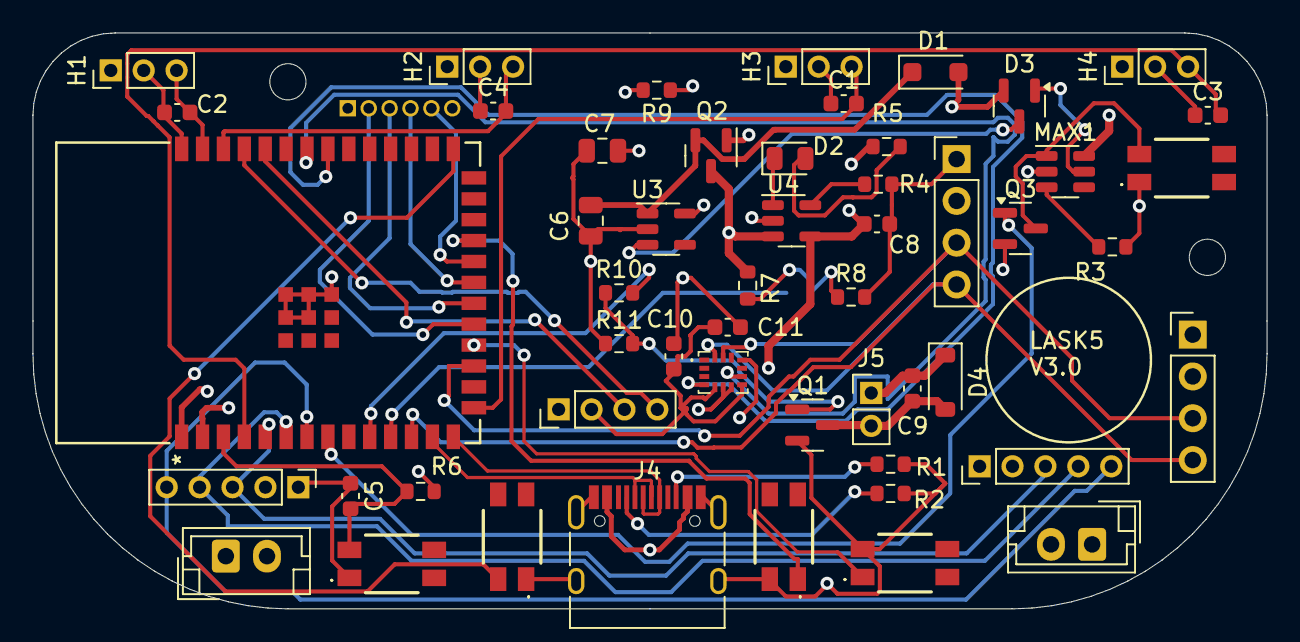
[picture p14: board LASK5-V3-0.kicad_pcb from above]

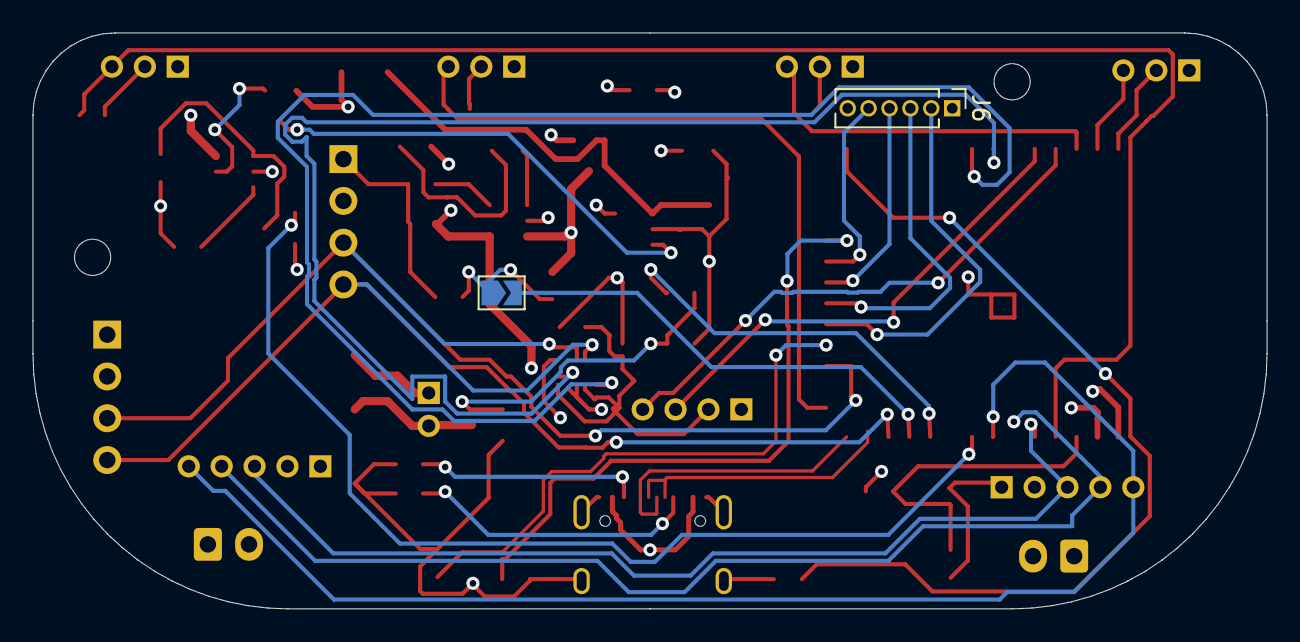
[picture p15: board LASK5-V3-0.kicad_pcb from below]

Board: 4 copper layers, 75.0 x 35.0 mm, 56 parts (2 on the bottom side), 44 nets.

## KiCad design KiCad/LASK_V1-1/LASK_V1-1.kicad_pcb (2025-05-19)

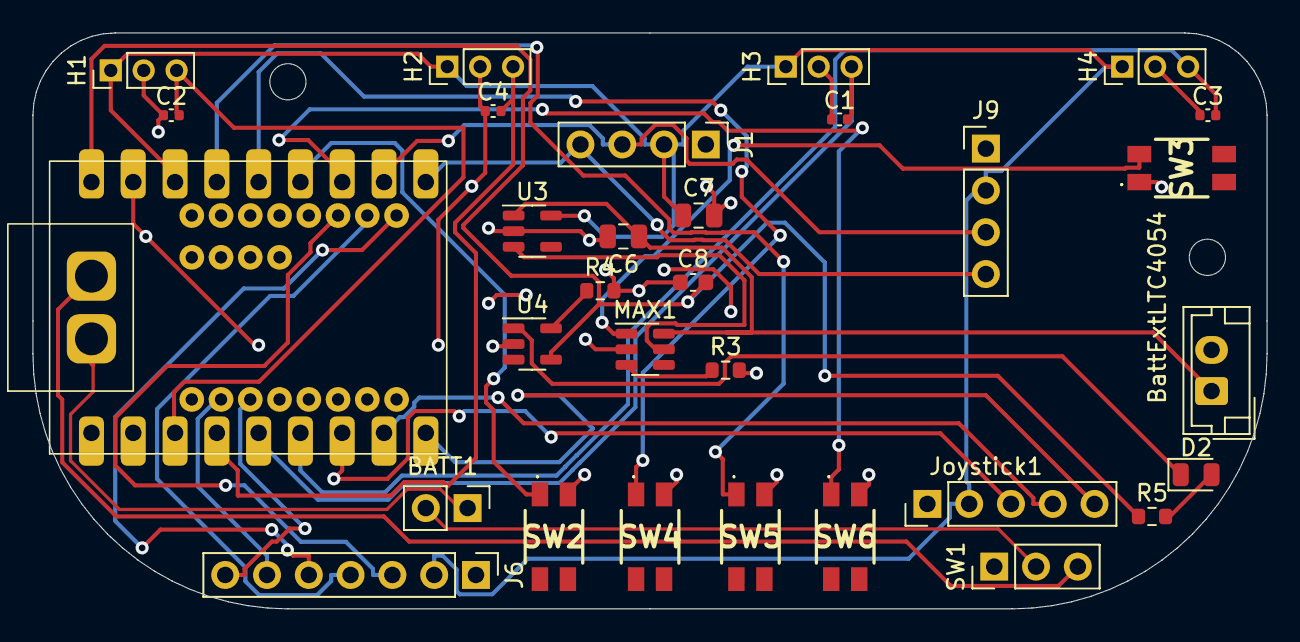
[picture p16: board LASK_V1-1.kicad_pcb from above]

Board: 2 copper layers, 75.0 x 35.0 mm, 33 parts (0 on the bottom side), 31 nets.

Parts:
BATT1: Conn_01x02_Pin; PinHeader_1x02_P2.54mm_Vertical
BattExtLTC4054: JST_02; JST_EH_B2B-EH-A_1x02_P2.50mm_Vertical
C1, C2, C3, C4: 100 nF; C_0402_1005Metric
C6, C7: 4.7uF; C_0805_2012Metric
C8: 2.2 uF; C_0603_1608Metric
D2: LED GREEN; LED_0805_2012Metric
H1, H2, H3, H4: A1369xUA-10; PinHeader_1x03_P2.00mm_Vertical
H7, H8: MountingHole; MountingHole_2.2mm_M2
J1, J9: Conn_01x04; PinHeader_1x04_P2.54mm_Vertical
J6: Conn_01x07_Pin; PinHeader_1x07_P2.54mm_Vertical
Joystick1: Conn_01x05_Pin; PinHeader_1x05_P2.54mm_Vertical
MAX1: SOT-23-6
R3: 1K; R_0603_1608Metric
R4: 2.7k; R_0603_1608Metric
R5: 150; R_0603_1608Metric
SW1: SW_SPDT; PinHeader_1x03_P2.54mm_Vertical
SW2, SW3, SW4, SW5, SW6: SW_Push; EVQP2P02M
U1: ESP32-S3-Super Mini
U3: TPS7A03; SOT-23-5
U4: LTC4054ES5-4.2; TSOT-23-5

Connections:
+3V3: C7.1, H1.1 (VCC), H2.1 (VCC), H3.1 (VCC), H4.1 (VCC), J1.2, J6.2, J9.2, Joystick1.2, U1.103 (3V3), U3.5 (OUT)
+3V8: BattExtLTC4054.1, C6.1, MAX1.6 (Vcc), U3.1 (IN)
+5V: C8.2, R5.1, U1.105 (5V), U4.4 (V_{CC})
BPACK+: BATT1.2, SW1.2 (B)
BPACK-: BATT1.1, U1.384 (BAT-)
BPACKSW+: SW1.3 (C), U1.385 (BAT+)
GND: BattExtLTC4054.2, C1.1, C2.1, C3.1, C4.1, C6.2, C7.2, C8.1, H1.2 (GND), H2.2 (GND), H3.2 (GND), H4.2 (GND), J1.1, J6.1, J9.1, Joystick1.1, MAX1.2 (GND), R3.2, R4.2, SW2.2, SW3.1, SW4.2, SW5.2, SW6.2, U1.100 (GND), U3.2 (GND), U4.2 (GND)
GP14: J6.5, U1.14
GP15: J6.4, U1.15
GP16: J6.3, U1.16
GP46: J6.7, U1.46
GP47: J6.6, U1.47
JSW: Joystick1.5, U1.7 (GP7)
JX: Joystick1.3, U1.5 (GP5)
JY: Joystick1.4, U1.6 (GP6)
LDO_EN: MAX1.5 (OUT), U3.3 (EN)
unnamed: D2.2 (A), R5.2
unnamed: D2.1 (K), U4.1 (~CHRG)
unnamed: MAX1.3 (CLEAR), R3.1
unnamed: R4.1, U4.5 (PROG)
RMT-BTN: MAX1.1 (In), SW3.2
SCL: J1.3, J9.3, U1.9 (GP9)
SDA: J1.4, J9.4, U1.8 (GP8)
b_left: SW4.1, U1.12 (GP12)
b_right: SW5.1, U1.13 (GP13)
b_select: SW6.1, U1.10 (GP10)
b_start: SW2.1, U1.11 (GP11)
hall_0: C2.2, H1.3 (VOUT), U1.1 (GP1)
hall_1: C4.2, H2.3 (VOUT), U1.2 (GP2)
hall_2: C1.2, H3.3 (VOUT), U1.3 (GP3)
hall_3: C3.2, H4.3 (VOUT), U1.4 (GP4)

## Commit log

2025-05-19 Base Files
    [BOM for OpenMuscle Labeler V0.csv, BOM for OpenMuscle Labeler V1.csv, EDI2CAP.CFG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]
2026-02-10 Add V3 schematic, backups; fix firmware path
    Add two KiCad backup ZIPs for LASK5 V3, add a JPG schematic (Open Muscle Labeler (LASK5) Schematic-V3.jpg), and update the existing PDF schematic. Also correct the README firmware link path to point to /embedded/LASK5 (adjusted capitalization) so it references the correct firmware directory in the OpenMuscle-Software repo.
2026-05-28 Update LASK5 V3 schematic and PCB; add design backups
    [LASK5-V3-0.kicad_pcb, LASK5-V3-0.kicad_sch]
2026-05-28 Add .gitignore for KiCad lock/autosave files

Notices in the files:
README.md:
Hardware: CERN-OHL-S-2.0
